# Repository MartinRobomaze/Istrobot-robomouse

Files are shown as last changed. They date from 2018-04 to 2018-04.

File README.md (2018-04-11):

## Welcome to GitHub Pages

You can use the [editor on GitHub](https://github.com/Martinlinux1/Istrobot-robomouse/edit/master/README.md) to maintain and preview the content for your website in Markdown files.

Whenever you commit to this repository, GitHub Pages will run [Jekyll](https://jekyllrb.com/) to rebuild the pages in your site, from the content in your Markdown files.

### Markdown

Markdown is a lightweight and easy-to-use syntax for styling your writing. It includes conventions for

```markdown
Syntax highlighted code block

# Header 1
## Header 2
### Header 3

- Bulleted
- List

1. Numbered
2. List

**Bold** and _Italic_ and `Code` text

[Link](url) and ![Image](src)
```

For more details see [GitHub Flavored Markdown](https://guides.github.com/features/mastering-markdown/).

### Jekyll Themes

Your Pages site will use the layout and styles from the Jekyll theme you have selected in your [repository settings](https://github.com/Martinlinux1/Istrobot-robomouse/settings). The name of this theme is saved in the Jekyll `_config.yml` configuration file.

### Support or Contact

Having trouble with Pages? Check out our [documentation](https://help.github.com/categories/github-pages-basics/) or [contact support](https://github.com/contact) and we’ll help you sort it out.

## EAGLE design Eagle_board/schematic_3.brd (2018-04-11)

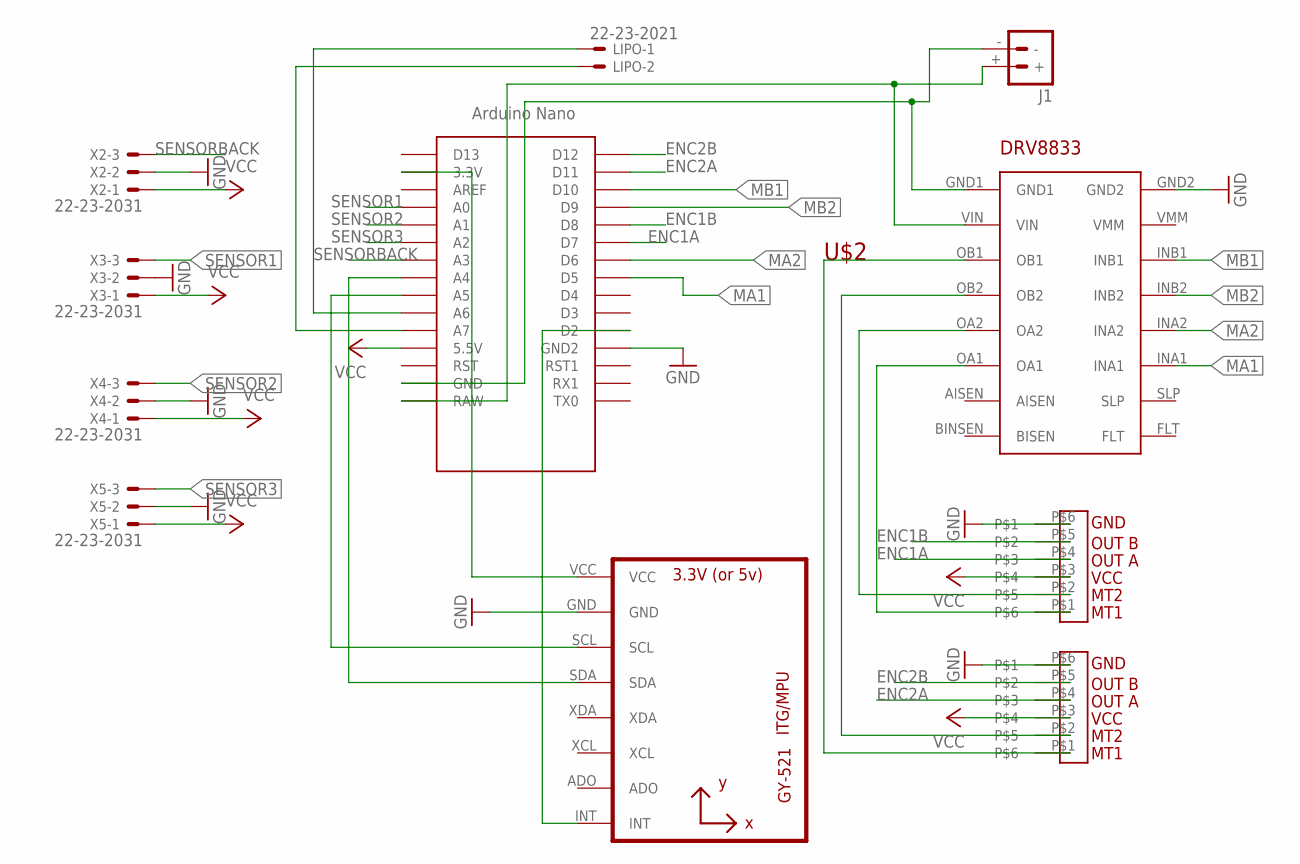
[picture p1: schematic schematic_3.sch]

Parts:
J1: BATTERY_CONN_DEANS; DEANS
LIPO: 22-23-2021
U1: GY-521MPU6050; GY-521
U$1: NANO
U$2: POLOLU-DRV8833
U$5, U$6: MOTOR; PINHEADER
X2, X3, X4, X5: 22-23-2031

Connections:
ENC1A: U$1.D7, U$5.P$4
ENC1B: U$1.D8, U$5.P$5
ENC2A: U$1.D11, U$6.P$4
ENC2B: U$1.D12, U$6.P$5
GND: U1.GND, U$1.GND1 (GND2), U$2.GND2, U$5.P$6, U$6.P$6, X2.2, X3.2, X4.2, X5.2
MA1: U$1.D5, U$2.INA1
MA2: U$1.D6, U$2.INA2
MB1: U$1.D10, U$2.INB1
MB2: U$1.D9, U$2.INB2
unnamed: J1.-, U$1.GND, U$2.GND1
unnamed: J1.+, U$1.RAW, U$2.VIN
unnamed: LIPO.1, U$1.A6
unnamed: LIPO.2, U$1.A7
unnamed: U1.VCC, U$1.3.3V
unnamed: U1.SCL, U$1.A5
unnamed: U1.SDA, U$1.A4
unnamed: U$2.OA2, U$5.P$2
unnamed: U$2.OA1, U$5.P$1
unnamed: U$2.OB2, U$6.P$2
unnamed: U$2.OB1, U$6.P$1
unnamed: U1.INT, U$1.D2
SENSOR1: U$1.A0, X3.3
SENSOR2: U$1.A1, X4.3
SENSOR3: U$1.A2, X5.3
SENSORBACK: U$1.A3, X2.3
VCC: U$1.5V (5.5V), U$5.P$3, U$6.P$3, X2.1, X3.1, X4.1, X5.1

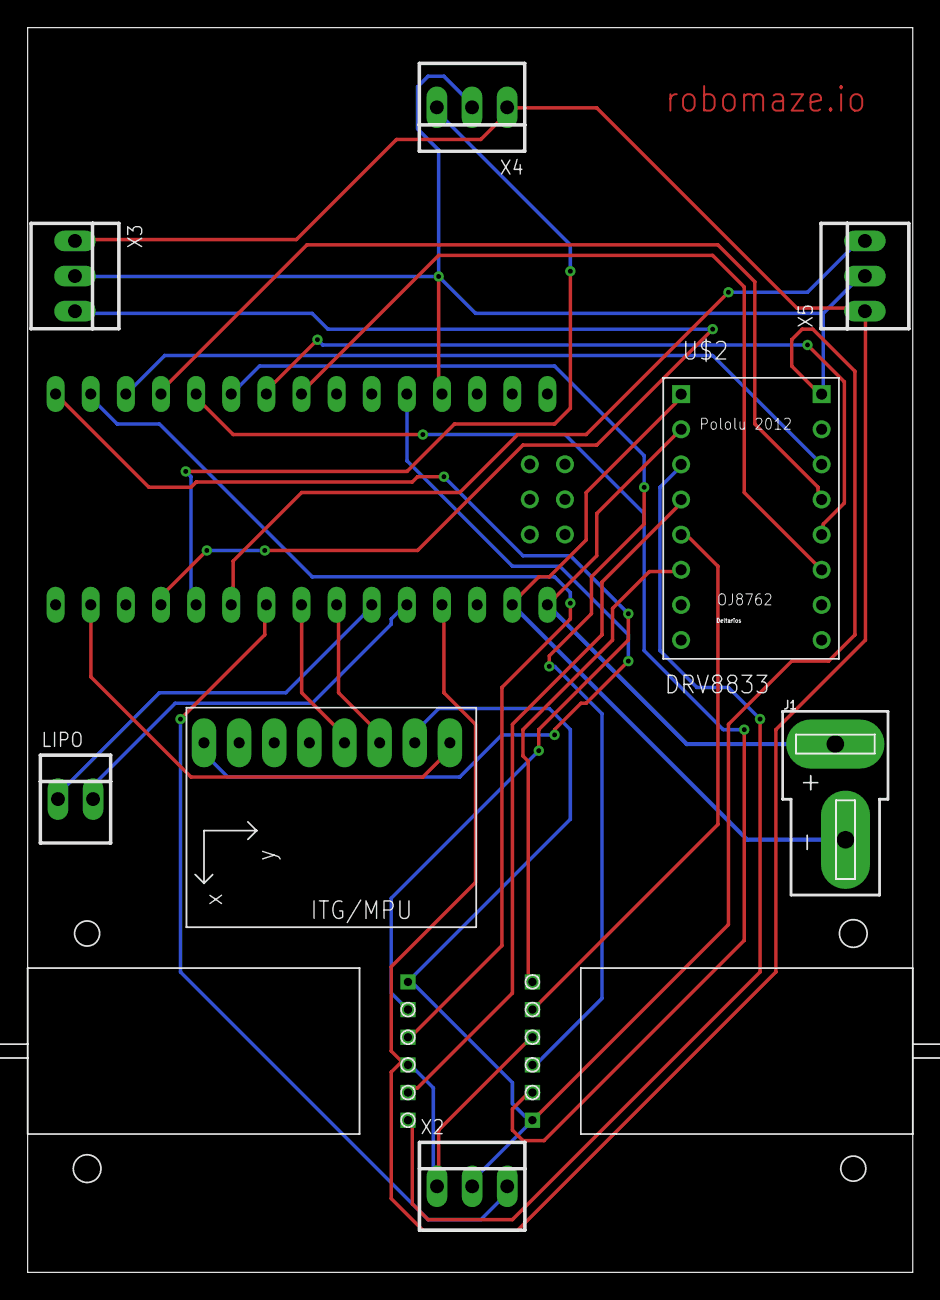
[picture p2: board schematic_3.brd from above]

Board: 2 copper layers, 64.0 x 90.0 mm, 11 parts (0 on the bottom side), 26 nets.

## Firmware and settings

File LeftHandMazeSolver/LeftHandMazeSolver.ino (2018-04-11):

#include <avr/sleep.h>
#include <MPU6050.h>
/*
 * This is maze solver program based on left hand rule with optimizing path
 * 
 * versions:
 * v0.1
 */

//char path[200];
//byte pathIndex = 0;
//byte readIndex = 0;

const byte baseSpeed = 60;

bool hasTurned = false;

int targetAngle = 0;


byte i = 0;


void setup() {
  begin();
  Serial.begin(9600);
  pinMode(A7, INPUT);
  while (analogRead(A7) != 1023) {}
  delay(1000);
}

void loop() {
  if (readIRSensor(2) < 0.6) {
    forward();
  } else {
    stop();
    forward();
    delay(50);
    stop();
    turn(90);
    forward();
    delay(50);
    stop();
  }
}

//void leftHandMazeSolve() {
//  if (readIRSensor(1) < 0.8) {
//    stop();
//    //forward(150, 0.5);
//    turn(150, -90);
//    forward(150, 1);
//    path[pathIndex] = 'L';
//  } else if (readIRSensor(2) < 0.8) {
//    straight(150);
//    if (readIRSensor(3) < 0.8) {
//      path[pathIndex]= 'S';
//    }
//  } else if (readIRSensor(3) < 0.8) {
//    stop();
//    //forward(150, 0.5);
//    turn(150, 90);
//    forward(150, 1);
//    path[pathIndex] = 'R';
//  } else {
//    turnTank(150, 180);
//    forward(150, 1);
//    path[pathIndex] = 'B';
//  }
//  pathIndex++;
//  shortPath();
//}
//
//
//void shortPath() {
//  if (path[pathIndex - 1] == 'B') {
//    if (path[pathIndex - 2] == 'L' && path[pathIndex] == 'L') {
//      pathIndex -= 3;
//      path[pathIndex] = 'S';
//    } else if (path[pathIndex - 2] == 'L' && path[pathIndex] == 'R') {
//      pathIndex -= 3;
//      path[pathIndex] = 'B';
//    } else if (path[pathIndex - 2] == 'L' && path[pathIndex] == 'S') {
//      pathIndex -= 3;
//      path[pathIndex] = 'R';
//    } else if (path[pathIndex - 2] == 'R' && path[pathIndex] == 'L') {
//      pathIndex -= 3;
//      path[pathIndex] = 'B';
//    } else if (path[pathIndex - 2] == 'S' && path[pathIndex] == 'L') {
//      pathIndex -= 3;
//      path[pathIndex] = 'R';
//    } else if (path[pathIndex - 2] == 'S' && path[pathIndex] == 'S') {
//      pathIndex -= 3;
//      path[pathIndex] = 'B';
//    }
//
//    pathIndex++;
//  } else {
//    return;
//  }
//}
//
//
//void repeatMotion() {
//  if ((readIRSensor(1) > .65 && readIRSensor(1) < .9) && (readIRSensor(3) > .65 && readIRSensor(3) < .9)) {
//    straight(255);
//  } else {
//    if (path[readIndex] == 'L') {
//      stop();
//      //forward(150, 0.5);
//      turn(200, -90);
//      forward(255, 1);
//    } else if (path[readIndex] == 'S') {
//      straight(255);
//    } else if (path[readIndex] == 'R') {
//      stop();
//      //forward(150, 0.5);
//      turn(150, 90);
//      forward(150, 1);
//    } else if (path[readIndex] == 'D') {
//      stop();
//      delay(1000);
//      moveTank(-255, 255); // pinky sa toci a toci a toci...
//    }
//  }
//}
//
//
//void straight(byte speed) {
//  byte speedA = speed - readEncoderPos('b');
//  byte speedB = speed + readEncoderPos('a');
//
//  moveTank(speedA, speedB);
//}
//
//void power_off() {
//  set_sleep_mode(SLEEP_MODE_PWR_DOWN);
//  sleep_enable();
//}

int getSpeed() {
  return baseSpeed;
}

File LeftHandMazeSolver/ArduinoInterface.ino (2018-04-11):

/****
 * This is program for motor control and sensor reading.
 * 
 * v0.1a - finished developing ArduinoInterface class
 * v0.1b - tested motor driving - sucessful
 * v0.1b2 - tested encoders - sucessful
 * v0.1b3 - tested compass reading - sucessful
 * v0.1b4 - replace left and right functions with pointTo(speed, angle) and turn(speed, angle)
 *          issue: compass reading is not good
 * v0.2a1 - replacing compass with gyro + accelerometer MPU6050 - using Jeff Rowberg's library - link: https://github.com/jrowberg/i2cdevlib/tree/master/Arduino/MPU6050
 * v0.2b1 - tested gyro - absolutely sucessful
 * creator: MartinLinux
 */

//include arduino library
#include <Arduino.h>
//include encoder library
#include <Encoder.h>


float PR, DR, previousIrError;
float PE, DE, previousEncError;
float PE2, DE2, previousEncError2;

const float kPR = 20, kDR = 10;
const float kPE = 1, kDE = .5;

int encError = 0;
int encError2;

//defining pins for motor control
const int motorBF = 5;
const int motorBB = 6;
const int motorAF = 10;
const int motorAB = 9;

//defining pins for sensor reading
const int sensors[4] = {A0, A1, A2, A3};

//defining pins for encoder reading
Encoder rotationsB(2, 8);
Encoder rotationsA(3, 12);

/**
 * function for initialize components
 */
void begin() {
  pinMode(motorAF, OUTPUT);
  pinMode(motorAB, OUTPUT);
  pinMode(motorBF, OUTPUT);
  pinMode(motorBB, OUTPUT);

  for (int i = 0; i < 4; i++) {
    pinMode(sensors[i], INPUT);
  }
}

/**
 * function for going forward until you stop motors manually
 */
void forward() {

  float speedA = getSpeed();
  float speedB = getSpeed();

  if (readIRSensor(1) > 0.8 && readIRSensor(3) > 0.8) {
    float irError = readIRSensor(1) - readIRSensor(3);
  
    PR = irError;
    DR = irError - previousIrError;
  
    previousIrError = irError;
  
    float irPid = (PR * kPR) - (DR * kDR);

    speedA = speedA + irPid;
    speedB = speedB - irPid;

    Serial.print("PID: ");
    Serial.println(irPid);
    Serial.print("A: ");
    Serial.println(speedA);
    Serial.print("B: ");
    Serial.println(speedB);
  }
  else {
    float encPid = 0;
  
    // The B encoder will return negative value so we have to 
    // add the value.
    encError = readEncoderPos('A') + readEncoderPos('B');
    // To prevent incrementing we define encError as global and to get
    // the current error value we discount the previous error value.
    encError -= previousEncError;
    
    PE = encError;
    DE = encError - previousEncError;
  
    encPid = (PE * kPE) - (DE * kDE);
    speedB += encPid;
    previousEncError = encError;
  }

  moveTank(speedA, speedB);
}

/**
 * function for going backward until you stop them manually
 */
void back(byte speed) {
  analogWrite(motorAF, 0);
  analogWrite(motorAB, speed);
  analogWrite(motorBF, 0);
  analogWrite(motorBB, speed);
}

/**
 * function for move robot like tank
 */
void moveTank(int speedA, int speedB) {

  if (speedA > 0) {
    analogWrite(motorAF, speedA);
    analogWrite(motorAB, 0);
  }
  else if (speedA < 0) {
    analogWrite(motorAF, 0);
    analogWrite(motorAB, speedA);
  }
  else {
    analogWrite(motorAF, 0);
    analogWrite(motorAB, 0);
  }
 
  if (speedB > 0) {
    analogWrite(motorBF, speedB);
    analogWrite(motorBB, 0);
  }
  else if (speedB < 0) {
    analogWrite(motorBF, 0);
    analogWrite(motorBB, speedB);
  }
  else {
    analogWrite(motorBF, 0);
    analogWrite(motorBB, 0);
  }
}

/**
 * turn left/right
 */
void turn(float angle) {
  int originalPosA = readEncoderPos('A');
  int originalPosB = readEncoderPos('B');
  
  if (angle == 90) {
    int compensation = getSpeed() < 200 ? 80 : 230;
    while (readEncoderPos('A') - originalPosA < 441 - compensation) {
      moveTank(getSpeed() + 20, 0);
      Serial.println(readEncoderPos('A'));
    }
    
    stop();
  } else if (angle == -90) {
    int compensation = getSpeed() < 200 ? 140 : 200;
    while (readEncoderPos('B') + 20 - originalPosB > -441 + compensation) {
      moveTank(0, getSpeed);
    }
    
    stop();
  }
  rotationsA.write(0);
  rotationsB.write(0);
}

/**
 * stop motors
 */
void stop() {
  digitalWrite(motorAF, 1);
  digitalWrite(motorAB, 1);
  digitalWrite(motorBF, 1);
  digitalWrite(motorBB, 1);
  delay(3);
  digitalWrite(motorAF, 0);
  digitalWrite(motorAB, 0);
  digitalWrite(motorBF, 0);
  digitalWrite(motorBB, 0);
}

/**
 * reading IR sensors
 */
float readIRSensor(int sensor) {
  return analogRead(sensors[sensor - 1]) * 5.0 / 1024.0;
}

/**
 * reading rotary encoders
 */
float readEncoderPos(char sensor) {
  if (sensor == 'A') {
    return rotationsA.read();
  }
  else if (sensor == 'B') {
    return rotationsB.read();
  }
  else {
    return -999999999999;
  }
}

/**
 * transforms centimeters to rotations
 */
float getRotationsFromCm(float cm) {
  return (cm - 6) / (PI * 3);
}

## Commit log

2018-03-17 Made ArduinoInterface for communicate with arduino and tested motors
2018-03-31 ted encoders, finding issue with compass
    [ArduinoInterface.ino, LeftHandMazeSolver.ino]
2018-03-31 fixed issue with compass - replace it with gyro(mpu6050), testing gyro - sucesfull
    [ArduinoInterface.ino, LeftHandMazeSolver.ino]
2018-04-01 Added PCB and schematic
    [schematic.brd, schematic.sch, schematic_2.sch]
2018-04-01 finished PCB
    [schematic_2.brd]

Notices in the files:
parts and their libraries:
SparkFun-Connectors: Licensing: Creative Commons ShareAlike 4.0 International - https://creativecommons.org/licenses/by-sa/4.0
